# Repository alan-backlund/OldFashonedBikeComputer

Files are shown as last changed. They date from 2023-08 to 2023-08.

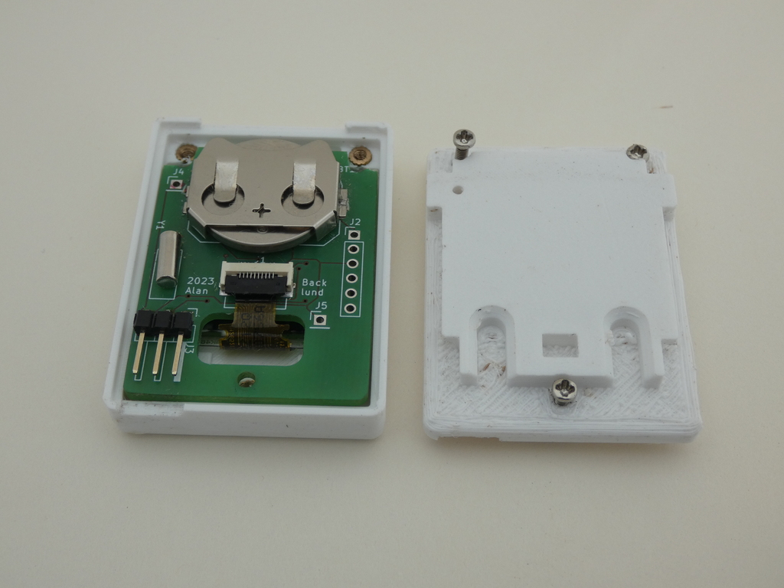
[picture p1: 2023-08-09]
Photos/P17.JPG

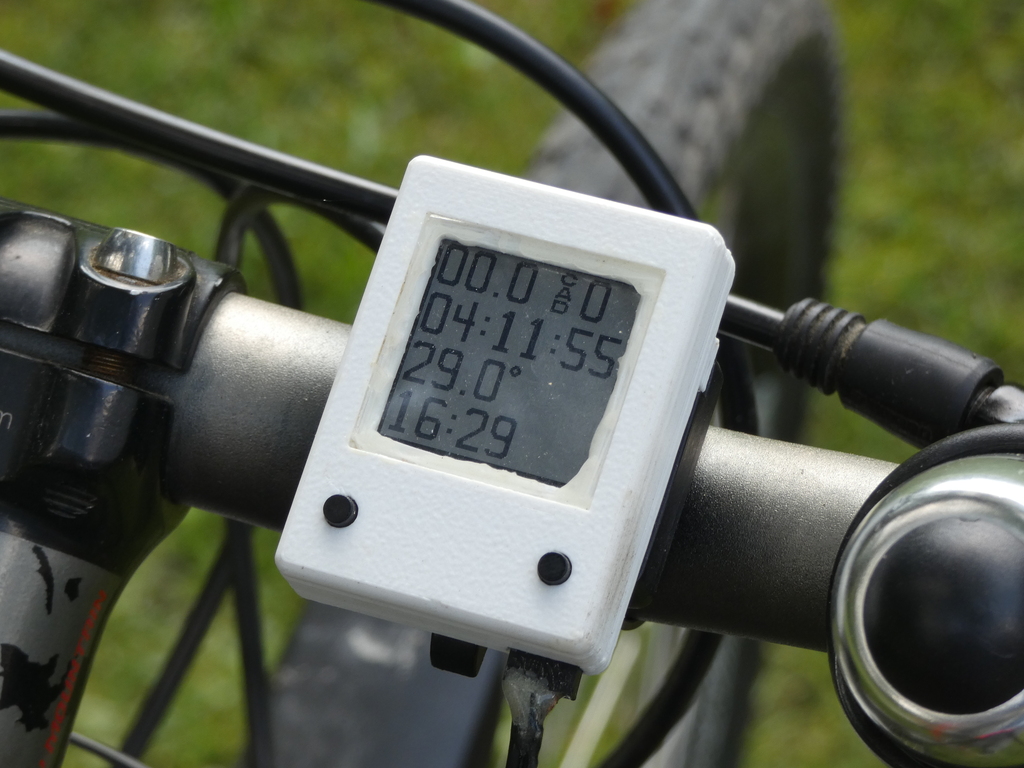
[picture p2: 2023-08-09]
Photos/P08.JPG

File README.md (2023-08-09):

# OldFashonedBikeComputer
Bicycle computer like they don't make anymore. Distance &amp; cadence and a battery that lasts years.

## Overview
OldFashonedBikeComputer (OFBC) is a bicycle computer based on the STM32L031 mpu and a Sharp LS013B7DH03 display. It monitors distance travelled, cadence and temperature. It fits in a small (35mm by 55mm) case and will hopefully run for two years on a CR2032 coin cell.

### The State of This Project
I have built a unit and am using it on my bike. IT works "Good enough" for my requirements so I am moving on to other projects for now. A number of options are set the way I like them and can only be changed by re-compiling the firmware.

### To Do
* Larger screen.
* Switch to a processor with more flash (32k is barely enough).
* More configuration items (kilometres/miles, Celsuis/Farenheit, 12hr/24hr).
* New PCB with the mounting holes in the right place. Original pcb has been literally hacked to fit.

## Contributing
If you have a suggestion for an improvement, please fork the repo and create a pull request. You can also simply open an issue or for more general feature requests, head over to the discussions.

## License
Distributed under the GPL v3 License.

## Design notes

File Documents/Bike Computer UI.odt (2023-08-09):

Bicycle Computer

User Interface

2023-08-09

# Initial Screen

Shows build Date

Exits when either key is pressed or either sensor is triggered.

# Prime screen

Shows items of interest while riding.

Currently Speed, cadence, ride duration, temperature and clock.

| Left Button | Right Button
Short Press | Switch to secondary screen | Not used
Long Press | Switch to setup selection screen | Reset Ride distance, time & max. speed

# Secondary Screen

Shows items of interest while stopped.

Currently ride distance, ride maximum speed, ride duration and odometer.

| Left Button | Right Button
Short Press | Switch to prime screen | Not used
Long Press | Switch to setup selection screen | Reset Ride distance, time & max. speed

# Setup Selection Screen

Used to select parameter to be set up.

| Left Button | Right Button
Short Press | Change selected item | Switch to selected item
Long Press | Not used | Return to primary or secondary screen

# Clock Setup Screen

Used to set clock.

| Left Button | Right Button
Short Press | Change selected item | Increment to selected item
Long Press | Not used | Return to primary or secondary screen

# Odometer Setup Screen

Used to set odometer.

| Left Button | Right Button
Short Press | Change selected item | Increment to selected item
Long Press | Not used | Return to primary or secondary screen

# Wheel Diameter Setup Screen

Used to set wheel diameter used to calculate distance.

| Left Button | Right Button
Short Press | Change selected item | Increment to selected item
Long Press | Not used | Return to primary or secondary screen

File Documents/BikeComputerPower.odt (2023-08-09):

Bike Computer Power

# 2032 Battery

3V lithium

210-230 mAh

# Power

July 25, 2023

| Mode | µAmps | Hours | Days
CPU | 2.097MHz | 500 | 440 | 18.33
| Sleep | 17 | 12941.18 | 539.22
Display | Run | 2
| Sleep | 0.02
Temperature | Run | 9
| Sleep | 0.1
Total | Run | 511 | 430.53 | 17.94
| Sleep | 17.12 | 12849.5 | 535.4

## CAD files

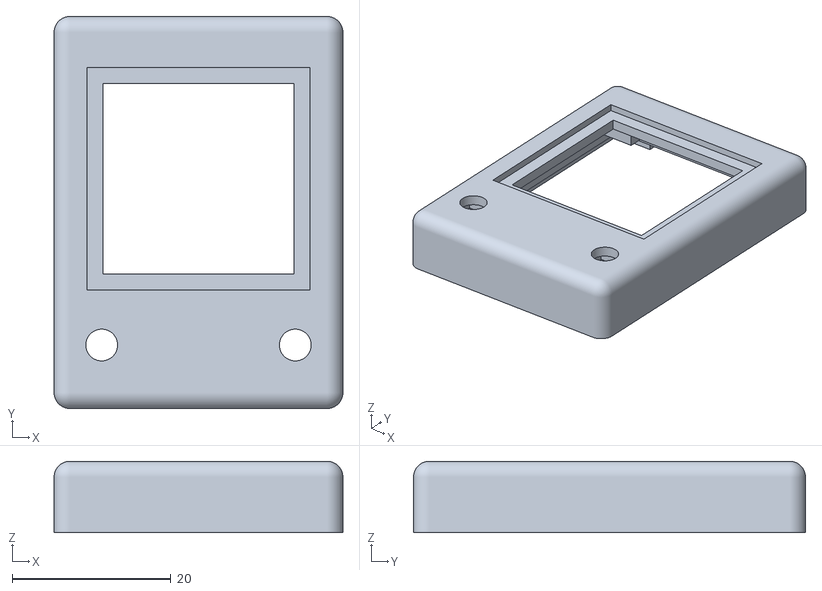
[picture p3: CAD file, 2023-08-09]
Case/caseTopV1.stl
36.4 x 49.4 x 9.00

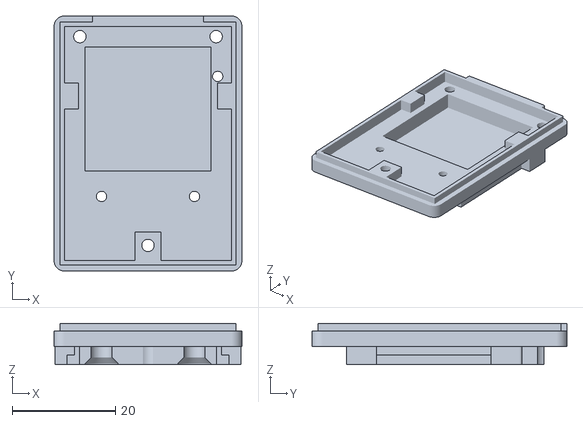
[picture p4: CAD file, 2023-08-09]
Case/caseBottomV1.stl
36.4 x 49.4 x 7.95

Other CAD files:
Case/caseTopV1.dxf

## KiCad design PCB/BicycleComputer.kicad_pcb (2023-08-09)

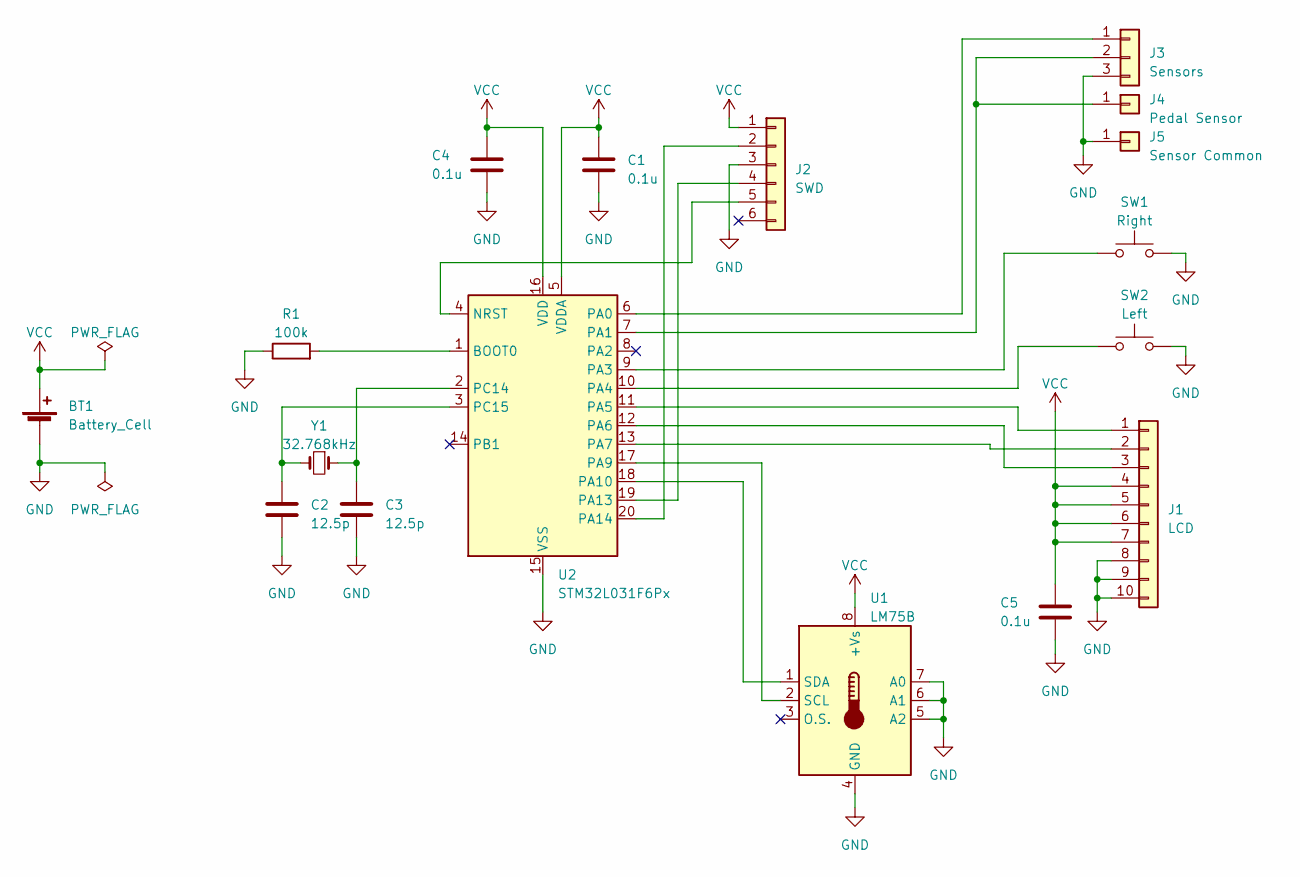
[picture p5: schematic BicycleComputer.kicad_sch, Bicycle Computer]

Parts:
BT1: Battery_Cell; BatteryHolder_Keystone_3034_1x20mm
C1, C4, C5: 0.1u; C_0805_2012Metric
C2, C3: 12.5p; C_0805_2012Metric
J1: LCD; Hirose_FH12-10S-0.5SH_1x10-1MP_P0.50mm_Horizontal
J2: SWD; PinHeader_1x06_P2.54mm_Vertical
J3: Sensors; PinHeader_1x03_P2.54mm_Horizontal
J4: Pedal Sensor; PinHeader_1x01_P2.54mm_Vertical
J5: Sensor Common; PinHeader_1x01_P2.54mm_Vertical
R1: 100k; R_0805_2012Metric
SW1: Right; SW_Push_1P1T_NO_6x6mm_H9.5mm
SW2: Left; SW_Push_1P1T_NO_6x6mm_H9.5mm
U1: LM75B; HVSSOP-8-1EP_3x3mm_P0.65mm_EP1.57x1.89mm
U2: STM32L031F6Px; TSSOP-20_4.4x6.5mm_P0.65mm
Y1: 32.768kHz; Crystal_C38-LF_D3.0mm_L8.0mm_Horizontal

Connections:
GND: BT1.2 (-), C1.2, C2.2, C3.2, C4.2, C5.2, J1.8, J1.9, J1.10, J2.3, J3.3, J5.1, R1.1, SW1.2, SW2.2, U1.4 (GND), U1.5 (A2), U1.6 (A1), U1.7 (A0), U2.15 (VSS)
unnamed: J1.1, U2.11 (PA5)
unnamed: J1.2, U2.13 (PA7)
unnamed: J1.3, U2.12 (PA6)
unnamed: J2.2, U2.20 (PA14)
unnamed: J2.4, U2.19 (PA13)
unnamed: J2.5, U2.4 (NRST)
unnamed: J3.1, U2.6 (PA0)
unnamed: J3.2, J4.1, U2.7 (PA1)
unnamed: U1.2 (SCL), U2.17 (PA9)
unnamed: U1.1 (SDA), U2.18 (PA10)
unnamed: R1.2, U2.1 (BOOT0)
unnamed: SW1.1, U2.9 (PA3)
unnamed: SW2.1, U2.10 (PA4)
unnamed: C3.1, U2.2 (PC14), Y1.1
unnamed: C2.1, U2.3 (PC15), Y1.2
VCC: BT1.1 (+), C1.1, C4.1, C5.1, J1.4, J1.5, J1.6, J1.7, J2.1, U1.8 (+Vs), U2.5 (VDDA), U2.16 (VDD)

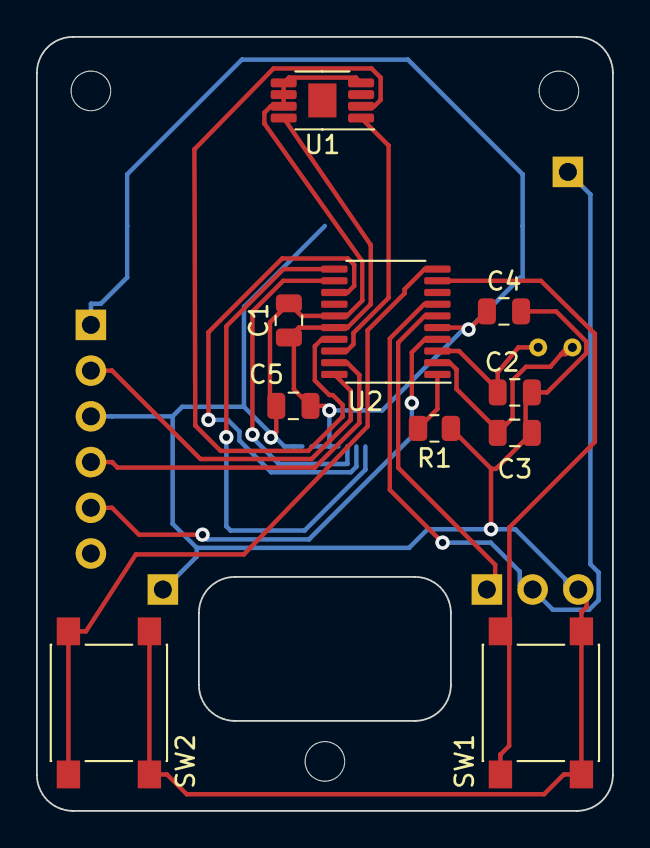
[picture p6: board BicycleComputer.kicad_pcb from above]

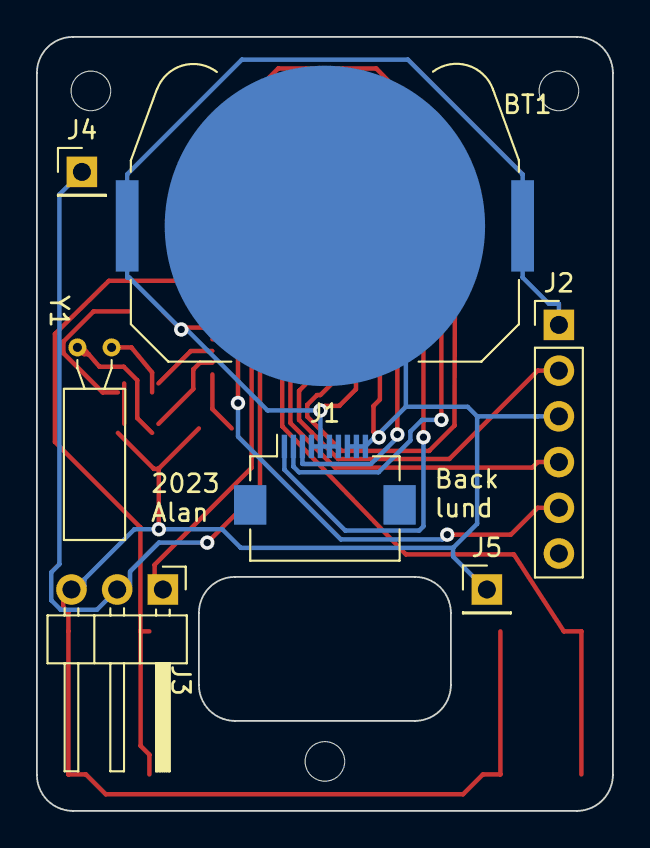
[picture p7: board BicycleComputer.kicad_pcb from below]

Board: 2 copper layers, 32.0 x 43.0 mm, 20 parts (7 on the bottom side), 17 nets.

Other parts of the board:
REF00, REF01, REF02: MountingHole_2.2mm_M2

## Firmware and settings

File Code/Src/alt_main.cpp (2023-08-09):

/* Includes ------------------------------------------------------------------*/
#include "alt_main.h"

/* Private includes ----------------------------------------------------------*/
#include "monitor.hpp"
#include "sharp_display.h"
#include <Temperature_LM75_Derived.h>
#include "bitmaps.h"
#include "gpio.h"
#include "spi.h"
#include "rtc.h"
#include "main.h"


/* Private typedef -----------------------------------------------------------*/

typedef struct
{
	uint16_t Pin;
	GPIO_PinState Value;
	uint32_t Time;
} SwitchTime_t;

typedef struct {
	uint8_t hours;
	uint8_t minutes;
	uint8_t seconds;
} TOD_t;

enum class State_t { STOPPED, RUNNING, SETUP };

enum class Command_t { LEFT_SHORT, LEFT_LONG, RIGHT_SHORT, RIGHT_LONG };

enum class Display_t { RIDE, INFO };

enum class SetUpScreen_t { MAIN, CLOCK, ODO, WHEEL };

/* Private define ------------------------------------------------------------*/

#define USE_SLEEP	1

#define SHORT_MIN	100	// mS
#define SHORT_MAX	800
#define LONG_MIN	1000
#define LONG_MAX	3500

#define CHECK			0xAB200723
#define CHECK_ADR		0x08080000
#define WHEEL_ADR		(CHECK_ADR + 4)
#define ODOMETER_ADR	(CHECK_ADR + 8)

#define readFromEEPROMi16(address)		(*(__IO int16_t *)(address))
#define readFromEEPROMu32(address)		(*(__IO uint32_t *)(address))

/* Private macro -------------------------------------------------------------*/

/* Private variables ---------------------------------------------------------*/
cMonitor monitor;
sharp_display display(SPI1_CS_GPIO_Port, SPI1_CS_Pin, &hspi1);
Generic_LM75_11Bit temperature(&hi2c1);

volatile State_t systemState = State_t::STOPPED;

#if 0
volatile SwitchTime_t controlQ[16];
volatile uint8_t controlH = 0, controlT = 0;
#else
GPIO_PinState leftLastState = GPIO_PIN_SET;
GPIO_PinState rightLastState = GPIO_PIN_SET;
#endif
volatile SwitchTime_t sensorQ[16];
volatile uint8_t sensorH = 0, sensorT = 0;
volatile uint32_t lastCqTime = 0;

volatile uint32_t Distance = 0;
volatile uint32_t SpdLastTime = 0;
volatile uint32_t Speed = 0;
volatile uint32_t MaximumSpeed = 0;
volatile uint32_t CadLastTime = 0;
volatile uint32_t Cadence = 0;
volatile uint32_t Duration = 0;
volatile uint32_t Odometer = 0;

volatile uint32_t leftStartTime = 0;
volatile uint32_t rightStartTime = 0;

volatile Display_t currentDisplay = Display_t::RIDE;

volatile SetUpScreen_t setupScreen = SetUpScreen_t::MAIN;
volatile uint8_t setupSelection = 0;

volatile int16_t wheelDiameter = 2125;

char clockText[] = "24:00";
char OdometerText[] = "0000.0";
char wheelDiameterText[] = "2125";

/* Private function prototypes -----------------------------------------------*/

/* Private user code ---------------------------------------------------------*/

void drawSpeed(int16_t x, int16_t y)
{
	display.drawBitmap(&x, y, &bitmaps32[(Speed/100)%10]);
	display.drawBitmap(&x, y, &bitmaps32[(Speed/10)%10]);
	display.drawBitmap(&x, y, &bitmaps32[period_idx]);
	display.drawBitmap(&x, y, &bitmaps32[(Speed/1)%10]);
}

void drawMaximumSpeed(int16_t x, int16_t y)
{
	display.drawBitmap(&x, y, &bitmaps32[max_idx]);
	display.drawBitmap(&x, y, &bitmaps32[(MaximumSpeed/100)%10]);
	display.drawBitmap(&x, y, &bitmaps32[(MaximumSpeed/10)%10]);
	display.drawBitmap(&x, y, &bitmaps32[period_idx]);
	display.drawBitmap(&x, y, &bitmaps32[(MaximumSpeed/1)%10]);
}

void drawCadence(int16_t x, int16_t y)
{
	display.drawBitmap(&x, y, &bitmaps32[cad_idx]);
	uint32_t d = (Cadence/100)%10;
	if (d != 0)
		display.drawBitmap(&x, y, &bitmaps32[d]);
	d = (Cadence/10)%10;
	if (d != 0)
		display.drawBitmap(&x, y, &bitmaps32[d]);
	display.drawBitmap(&x, y, &bitmaps32[(Cadence/1)%10]);
}

void drawDistance(int16_t x, int16_t y)
{
	display.drawBitmap(&x, y, &bitmaps32[dst_idx]);
	uint32_t dist = Distance*wheelDiameter/10000;
	uint32_t d = (dist/10000)%10;
	if (d != 0)
		display.drawBitmap(&x, y, &bitmaps32[d]);
	d = (dist/1000)%10;
	if (d != 0)
		display.drawBitmap(&x, y, &bitmaps32[d]);
	display.drawBitmap(&x, y, &bitmaps32[(dist/100)%10]);
	display.drawBitmap(&x, y, &bitmaps32[period_idx]);
	display.drawBitmap(&x, y, &bitmaps32[(dist/10)%10]);
	display.drawBitmap(&x, y, &bitmaps32[(dist/1)%10]);
}

void drawDuration(int16_t x, int16_t y)
{
	int t = Duration / 1000;
	int s = t % 60;
	t = t / 60;
	int m = t % 60;
	int h = t / 60;

	display.drawBitmap(&x, y, &bitmaps32[(h/10)%10]);
	display.drawBitmap(&x, y, &bitmaps32[h%10]);
	display.drawBitmap(&x, y, &bitmaps32[colon_idx]);
	display.drawBitmap(&x, y, &bitmaps32[(m/10)%10]);
	display.drawBitmap(&x, y, &bitmaps32[m%10]);
	display.drawBitmap(&x, y, &bitmaps32[colon_idx]);
	display.drawBitmap(&x, y, &bitmaps32[(s/10)%10]);
	display.drawBitmap(&x, y, &bitmaps32[s%10]);
}

void drawTime(int16_t x, int16_t y)
{
	RTC_DateTypeDef sdatestructureget;
	RTC_TimeTypeDef stimestructureget;
	HAL_RTC_GetTime(&hrtc, &stimestructureget, RTC_FORMAT_BIN);
	HAL_RTC_GetDate(&hrtc, &sdatestructureget, RTC_FORMAT_BIN);
	display.drawBitmap(&x, y, &bitmaps32[(stimestructureget.Hours/10)%10]);
	display.drawBitmap(&x, y, &bitmaps32[stimestructureget.Hours%10]);
	display.drawBitmap(&x, y, &bitmaps32[colon_idx]);
	display.drawBitmap(&x, y, &bitmaps32[(stimestructureget.Minutes/10)%10]);
	display.drawBitmap(&x, y, &bitmaps32[stimestructureget.Minutes%10]);
}

void drawTemperature(int16_t x, int16_t y)
{
	temperature.disableShutdownMode();
	HAL_Delay(10);
	float t = temperature.readTemperatureC();
	temperature.enableShutdownMode();

	if (t < 0)
		t = -t;
	display.drawBitmap(&x, y, &bitmaps32[((int)t/10)%10]);
	display.drawBitmap(&x, y, &bitmaps32[(int)t%10]);
	display.drawBitmap(&x, y, &bitmaps32[period_idx]);
	display.drawBitmap(&x, y, &bitmaps32[(int)(t*10)%10]);
	display.drawBitmap(&x, y, &bitmaps32[degree_idx]);
}

void drawOdometer(int16_t x, int16_t y)
{
	display.drawBitmap(&x, y, &bitmaps32[odo_idx]);
	uint32_t dist = Odometer*wheelDiameter/100000;
	uint32_t d = (dist/10000)%10;
	if (d != 0)
		display.drawBitmap(&x, y, &bitmaps32[d]);
	d = (dist/1000)%10;
	if (d != 0)
		display.drawBitmap(&x, y, &bitmaps32[d]);
	d = (dist/100)%10;
	if (d != 0)
		display.drawBitmap(&x, y, &bitmaps32[d]);
	display.drawBitmap(&x, y, &bitmaps32[(dist/10)%10]);
	display.drawBitmap(&x, y, &bitmaps32[period_idx]);
	display.drawBitmap(&x, y, &bitmaps32[(dist/1)%10]);
}

void DisplaySetup()
{
	switch (setupScreen) {
	case SetUpScreen_t::MAIN:
		display.clearDisplay();
		display.drawBitmap(0, setupSelection*32, bitmaps32[rarrow_idx].bitmap, 18, 32, 0);
		display.drawString(18, 0, bitmaps32, (char *)"CLOCK");
		display.drawString(18, 32, bitmaps32, (char *)"ODO");
		display.drawString(18, 64, bitmaps32, (char *)"WHEEL");
		display.refresh();
		break;
	case SetUpScreen_t::CLOCK: {
		RTC_DateTypeDef sdatestructureget;
		RTC_TimeTypeDef stimestructureget;
		HAL_RTC_GetTime(&hrtc, &stimestructureget, RTC_FORMAT_BIN);
		HAL_RTC_GetDate(&hrtc, &sdatestructureget, RTC_FORMAT_BIN);
		clockText[0] = '0' + stimestructureget.Hours / 10;
		clockText[1] = '0' + stimestructureget.Hours % 10;
		clockText[2] = ':';
		clockText[3] = '0' + stimestructureget.Minutes / 10;
		clockText[4] = '0' + stimestructureget.Minutes % 10;
		display.clearDisplay();
		display.drawString(0, 0, bitmaps32, (char *)"CLOCK");
		display.drawString(0, 32, bitmaps32, clockText);
		display.drawBitmap(setupSelection*18, 64, bitmaps32[uarrow_idx].bitmap, 18, 32, 0);
		display.refresh();
	} break;
	case SetUpScreen_t::ODO: {
		uint32_t odo = Odometer*wheelDiameter/100000;
		OdometerText[0] = '0' + odo/10000;
		OdometerText[1] = '0' + (odo/1000) % 10;
		OdometerText[2] = '0' + (odo/100) % 10;
		OdometerText[3] = '0' + (odo/10) % 10;
		OdometerText[4] = '.';
		OdometerText[5] = '0' + odo % 10;
		display.clearDisplay();
		display.drawString(0, 0, bitmaps32, (char *)"ODO");
		display.drawString(0, 32, bitmaps32, OdometerText);
		display.drawBitmap(setupSelection*18, 64, bitmaps32[uarrow_idx].bitmap, 18, 32, 0);
		display.refresh();
	} break;
	case SetUpScreen_t::WHEEL:
		wheelDiameterText[0] = '0' + wheelDiameter/1000;
		wheelDiameterText[1] = '0' + (wheelDiameter/100) % 10;
		wheelDiameterText[2] = '0' + (wheelDiameter/10) % 10;
		wheelDiameterText[3] = '0' + wheelDiameter % 10;
		display.clearDisplay();
		display.drawString(0, 0, bitmaps32, (char *)"WHEEL");
		display.drawString(0, 32, bitmaps32, wheelDiameterText);
		display.drawBitmap(setupSelection*18, 64, bitmaps32[uarrow_idx].bitmap, 18, 32, 0);
		display.refresh();
		break;
	}
}

void CommandProcess(Command_t cmd)
{
	if (systemState != State_t::SETUP) {
		if (cmd == Command_t::RIGHT_LONG) {
			// reset time and CadCount
			Distance = 0;
			MaximumSpeed = 0;
			Duration = 0;
			monitor.schedule((char*)"DisplayUpdate", 0);
		} else if (cmd == Command_t::LEFT_SHORT) {
			if (currentDisplay == Display_t::RIDE)
				currentDisplay = Display_t::INFO;
			else
				currentDisplay = Display_t::RIDE;
			monitor.schedule((char*)"DisplayUpdate", 0);
		} else if (cmd == Command_t::LEFT_LONG) {
			systemState = State_t::SETUP;
			monitor.schedule((char*)"DisplayUpdate", NEVER);
			setupScreen = SetUpScreen_t::MAIN;
			setupSelection = 0;
			DisplaySetup();
		} else if (cmd == Command_t::RIGHT_SHORT) {
		}
	} else {
		if (cmd == Command_t::RIGHT_SHORT) {
			if (setupScreen == SetUpScreen_t::MAIN) {
				if (setupSelection == 0)
					setupScreen = SetUpScreen_t::CLOCK;
				else if (setupSelection == 1)
					setupScreen = SetUpScreen_t::ODO;
				else if (setupSelection == 2)
					setupScreen = SetUpScreen_t::WHEEL;
				setupSelection = 0;
				DisplaySetup();
			} else if (setupScreen == SetUpScreen_t::CLOCK) {
				// Change clock displayed value
				if (setupSelection == 0) {
					clockText[0]++;
					if (clockText[0] == '2' + 1)
						clockText[0] = '0';
				} else if (setupSelection == 1) {
					clockText[1]++;
					if (clockText[0] != '2') {
						if (clockText[1] == '9' + 1)
							clockText[1] = '0';
					} else {
						if (clockText[1] == '3' + 1)
							clockText[1] = '0';
					}
				} else if (setupSelection == 2) {
					clockText[3]++;
					if (clockText[3] == '5' + 1)
						clockText[3] = '0';
				} else if (setupSelection == 3) {
					clockText[4]++;
					if (clockText[4] == '9' + 1)
						clockText[4] = '0';
				}
				display.clearBlock(setupSelection*18 + ((setupSelection>1)?9:0), 32, 18, 32);
				display.drawString(0, 32, bitmaps32, clockText);
				display.refresh();
			} else if (setupScreen == SetUpScreen_t::ODO) {
				// Change odometer displayed value
				int ts = setupSelection + (setupSelection==4 ? 1:0);
				OdometerText[ts]++;
				if (OdometerText[ts] == '9' + 1)
					OdometerText[ts] = '0';
				display.clearBlock(ts*18, 32, 18, 32);
				display.drawString(0, 32, bitmaps32, OdometerText);
				display.refresh();
			} else if (setupScreen == SetUpScreen_t::WHEEL) {
				// Change wheel diameter displayed value
				wheelDiameterText[setupSelection]++;
				if (wheelDiameterText[setupSelection] == '9' + 1)
					wheelDiameterText[setupSelection] = '0';
				display.clearBlock(setupSelection*18, 32, 18, 32);
				display.drawString(0, 32, bitmaps32, wheelDiameterText);
				display.refresh();
			}
		} else if (cmd == Command_t::RIGHT_LONG) {
			if (setupScreen == SetUpScreen_t::CLOCK) {
				// Update clock value from display
				RTC_DateTypeDef sdatestructureget;
				RTC_TimeTypeDef stimestructureget;
				HAL_RTC_GetTime(&hrtc, &stimestructureget, RTC_FORMAT_BIN);
				HAL_RTC_GetDate(&hrtc, &sdatestructureget, RTC_FORMAT_BIN);
				stimestructureget.Hours = (clockText[0] - '0') * 10 + (clockText[1] - '0');
				stimestructureget.Minutes = (clockText[3] - '0') * 10 + (clockText[4] - '0');
				HAL_RTC_SetTime(&hrtc, &stimestructureget, RTC_FORMAT_BIN);
			} else if (setupScreen == SetUpScreen_t::ODO) {
				// Update odometer value from display
				uint32_t odo = (OdometerText[0] - '0') * 10000
						+ (OdometerText[1] - '0') * 1000
						+ (OdometerText[2] - '0') * 100
						+ (OdometerText[3] - '0') * 10
						+ (OdometerText[5] - '0');
				Odometer = odo*100000/wheelDiameter;
			} else if (setupScreen == SetUpScreen_t::WHEEL) {
				// Update wheel diameter value from display
				wheelDiameter = (wheelDiameterText[0] - '0') * 1000
						+ (wheelDiameterText[1] - '0') * 100
						+ (wheelDiameterText[2] - '0') * 10
						+ (wheelDiameterText[3] - '0');
				if (HAL_FLASHEx_DATAEEPROM_Unlock() == HAL_OK) {
					HAL_FLASHEx_DATAEEPROM_Program(FLASH_TYPEPROGRAMDATA_HALFWORD, WHEEL_ADR, wheelDiameter);
					HAL_FLASHEx_DATAEEPROM_Lock();
				}
			}

			systemState = State_t::RUNNING;
			monitor.schedule((char*)"DisplayUpdate", 0);
		} else if (cmd == Command_t::LEFT_SHORT) {
			if (setupScreen == SetUpScreen_t::MAIN) {
				display.drawBitmap(0, setupSelection*32, bitmaps32[rarrow_idx].bitmap, 18, 32, 1);
				setupSelection = (setupSelection + 1) % 3;
				display.drawBitmap(0, setupSelection*32, bitmaps32[rarrow_idx].bitmap, 18, 32, 0);
				display.refresh();
			} else if (setupScreen == SetUpScreen_t::CLOCK) {
				int16_t p = setupSelection * 18 + (setupSelection>1 ? 9 : 0);
				display.drawBitmap(p, 64, bitmaps32[uarrow_idx].bitmap, 18, 32, 1);
				setupSelection = (setupSelection + 1) % 4;
				p = setupSelection * 18 + ((setupSelection > 1) ? 9 : 0);
				display.drawBitmap(p, 64, bitmaps32[uarrow_idx].bitmap, 18, 32, 0);
				display.refresh();
			} else if (setupScreen == SetUpScreen_t::ODO) {
				int16_t p = setupSelection * 18 + (setupSelection>3 ? 9 : 0);
				display.drawBitmap(p, 64, bitmaps32[uarrow_idx].bitmap, 18, 32, 1);
				setupSelection = (setupSelection + 1) % 5;
				p = setupSelection * 18 + (setupSelection>3 ? 9 : 0);
				display.drawBitmap(p, 64, bitmaps32[uarrow_idx].bitmap, 18, 32, 0);
				display.refresh();
			} else if (setupScreen == SetUpScreen_t::WHEEL) {
				display.drawBitmap(setupSelection*18, 64, bitmaps32[uarrow_idx].bitmap, 18, 32, 1);
				setupSelection = (setupSelection + 1) % 4;
				display.drawBitmap(setupSelection*18, 64, bitmaps32[uarrow_idx].bitmap, 18, 32, 0);
				display.refresh();
			}
		} else if (cmd == Command_t::LEFT_LONG) {
		}
	}
}

timeInterval_t DisplayUpdate()
{
	uint32_t start = HAL_GetTick();

	if (Speed < 20) {
		Speed = 0;
		Cadence = 0;
	}
	if (Cadence < 20)
		Cadence = 0;
	if (systemState != State_t::STOPPED)
		Duration += 1000;

	display.clearDisplayBuffer();
	if (currentDisplay == Display_t::RIDE) {
		drawSpeed(0, 0);
		drawCadence(128-54, 0);
		drawTime(0, 128-1*32);
		drawTemperature(0, 128-2*32);
		drawDuration(0, 32);
	} else {
		drawDistance(0, 0);
		drawMaximumSpeed(0, 32);
		drawDuration(0, 32*2);
		drawOdometer(0, 32*3);
	}
	display.refresh();

	if (Speed > 0) {
		// calculate speed for next update, if no sensor update occurs
		RTC_TimeTypeDef stime;
		RTC_DateTypeDef sdate;
		HAL_RTC_GetTime(&hrtc, &stime, RTC_FORMAT_BIN);
		HAL_RTC_GetDate(&hrtc, &sdate, RTC_FORMAT_BIN);
		uint32_t now = stime.Hours * 1000 * 60 * 60;
		now += stime.Minutes * 1000 * 60;
		now += stime.Seconds * 1000;
		now += 1000 * (stime.SecondFraction - stime.SubSeconds) / (stime.SecondFraction + 1);
		Speed = ((uint32_t)(wheelDiameter*3.6*10))/(now - SpdLastTime);
	} else {
		systemState = State_t::STOPPED;
		if (HAL_FLASHEx_DATAEEPROM_Unlock() == HAL_OK) {
			HAL_FLASHEx_DATAEEPROM_Program(FLASH_TYPEPROGRAMDATA_WORD, ODOMETER_ADR, Odometer);
			HAL_FLASHEx_DATAEEPROM_Lock();
		}

		return NEVER;
	}

	if (Cadence > 0) {
		// calculate cadence for next update, if no sensor update occurs
		RTC_TimeTypeDef stime;
		RTC_DateTypeDef sdate;
		HAL_RTC_GetTime(&hrtc, &stime, RTC_FORMAT_BIN);
		HAL_RTC_GetDate(&hrtc, &sdate, RTC_FORMAT_BIN);
		uint32_t now = stime.Hours * 1000 * 60 * 60;
		now += stime.Minutes * 1000 * 60;
		now += stime.Seconds * 1000;
		now += 1000 * (stime.SecondFraction - stime.SubSeconds) / (stime.SecondFraction + 1);
		Cadence = 60000 / (sensorQ[sensorH].Time - CadLastTime);
	}

	return 1000 - (HAL_GetTick() - start);
}

timeInterval_t ControlUpdateLeft()
{
	timeInterval_t result = NEVER;
	if ((leftLastState == GPIO_PIN_SET) && (HAL_GPIO_ReadPin(GPIOA, LEFT_Pin) == GPIO_PIN_RESET)) {
		// left button has closed
		leftStartTime = HAL_GetTick();
		leftLastState = GPIO_PIN_RESET;
		result = 20;
	} else if ((leftLastState == GPIO_PIN_RESET) && (HAL_GPIO_ReadPin(GPIOA, LEFT_Pin) == GPIO_PIN_RESET)) {
		// left button still closed
		result = 20;
	} else if ((leftLastState == GPIO_PIN_RESET) && (HAL_GPIO_ReadPin(GPIOA, LEFT_Pin) == GPIO_PIN_SET)) {
		// left button has opened
		uint32_t dur = HAL_GetTick() - leftStartTime;
		leftStartTime = HAL_GetTick();
		if ((dur >= SHORT_MIN) && (dur <= SHORT_MAX))
			CommandProcess(Command_t::LEFT_SHORT);
		if ((dur >= LONG_MIN) && (dur <= LONG_MAX))
			CommandProcess(Command_t::LEFT_LONG);
		leftLastState = GPIO_PIN_SET;
		result = 20;
	} // else left button still opened => done (return NEVER)
	return result;
}

timeInterval_t ControlUpdateRight()
{
	timeInterval_t result = NEVER;
	if ((rightLastState == GPIO_PIN_SET) && (HAL_GPIO_ReadPin(GPIOA, RIGHT_Pin) == GPIO_PIN_RESET)) {
		// right button has closed
		rightStartTime = HAL_GetTick();
		rightLastState = GPIO_PIN_RESET;
		result = 20;
	} else if ((rightLastState == GPIO_PIN_RESET) && (HAL_GPIO_ReadPin(GPIOA, RIGHT_Pin) == GPIO_PIN_RESET)) {
		// right button still closed
		result = 20;
	} else if ((rightLastState == GPIO_PIN_RESET) && (HAL_GPIO_ReadPin(GPIOA, RIGHT_Pin) == GPIO_PIN_SET)) {
		// right button has opened
		uint32_t dur = HAL_GetTick() - rightStartTime;
		rightStartTime = HAL_GetTick();
		if ((dur >= SHORT_MIN) && (dur <= SHORT_MAX))
			CommandProcess(Command_t::RIGHT_SHORT);
		if ((dur >= LONG_MIN) && (dur <= LONG_MAX))
			CommandProcess(Command_t::RIGHT_LONG);
		rightLastState = GPIO_PIN_SET;
		result = 20;
	} // else right button still opened => done (return NEVER)
	return result;
}

timeInterval_t SensorUpdate()
{
	while (sensorH != sensorT) {
		if (sensorQ[sensorH].Pin == WHEEL_Pin) {
			if (systemState == State_t::RUNNING) {
				// max speed: 7.65/60kph => 0.1275s
				if ((sensorQ[sensorH].Time - SpdLastTime) > 127) {
					Speed = ((uint32_t)(wheelDiameter*3.6*10))/(sensorQ[sensorH].Time - SpdLastTime);
					if (Speed > MaximumSpeed)
						MaximumSpeed = Speed;
					Distance++;
					Odometer++;
					SpdLastTime = sensorQ[sensorH].Time;
				}
			} else if (systemState == State_t::STOPPED) {
				Speed = 1;
				SpdLastTime = sensorQ[sensorH].Time;
				systemState = State_t::RUNNING;
				monitor.schedule((char*)"DisplayUpdate", 500);
			}
			// else if CONTROL then do nothing
		}
		// max rpm: 60/300rpm => 0.2s
		if ((sensorQ[sensorH].Pin == PEDAL_Pin) && ((sensorQ[sensorH].Time - CadLastTime) > 200)) {
			Cadence = 60000 / (sensorQ[sensorH].Time - CadLastTime);
			CadLastTime = sensorQ[sensorH].Time;
		}
		sensorH = (sensorH + 1) & 0xF;
	}
	return NEVER;
}


task_t TasksTable[] = {
	{ (char *)"DisplayUpdate", DisplayUpdate, NEVER, false },
	{ (char *)"ControlUpdateLeft", ControlUpdateLeft, NEVER, false },
	{ (char *)"ControlUpdateRight", ControlUpdateRight, NEVER, false },
	{ (char *)"SensorUpdate", SensorUpdate, NEVER, false },
};

/**
  * @brief  System Clock Configuration
  *         The system Clock is configured as follow :
  *            System Clock source            = MSI
  *            MSI Range                      = 0
  *            SYSCLK(Hz)                     = 64000
  *            HCLK(Hz)                       = 32000
  *            AHB Prescaler                  = 2
  *            APB1 Prescaler                 = 1
  *            APB2 Prescaler                 = 1
  *            Main regulator output voltage  = Scale2 mode
  * @param  None
  * @retval None
  */
void SystemClock_Decrease(void)
{
	RCC_ClkInitTypeDef RCC_ClkInitStruct = {0};
	RCC_OscInitTypeDef RCC_OscInitStruct = {0};
	/* Enable Power Control clock */
	__HAL_RCC_PWR_CLK_ENABLE();

	/* The voltage scaling allows optimizing the power consumption when the device is
	 clocked below the maximum system frequency, to update the voltage scaling value
	 regarding system frequency refer to product datasheet.  */
	__HAL_PWR_VOLTAGESCALING_CONFIG(PWR_REGULATOR_VOLTAGE_SCALE2);

	/* Enable MSI Oscillator */
	RCC_OscInitStruct.OscillatorType = RCC_OSCILLATORTYPE_MSI;
	RCC_OscInitStruct.MSIState = RCC_MSI_ON;
	RCC_OscInitStruct.MSIClockRange       = RCC_MSIRANGE_5; /* Set temporary MSI range */
	RCC_OscInitStruct.MSICalibrationValue = RCC_MSICALIBRATION_DEFAULT;
	RCC_OscInitStruct.PLL.PLLState = RCC_PLL_NONE;
	if (HAL_RCC_OscConfig(&RCC_OscInitStruct)!= HAL_OK)
		Error_Handler();

	/* Select MSI as system clock source and configure the HCLK, PCLK1 and PCLK2
	 clocks dividers */
	RCC_ClkInitStruct.ClockType = (RCC_CLOCKTYPE_SYSCLK | RCC_CLOCKTYPE_HCLK | RCC_CLOCKTYPE_PCLK1 | RCC_CLOCKTYPE_PCLK2);
	RCC_ClkInitStruct.SYSCLKSource = RCC_SYSCLKSOURCE_MSI;
	RCC_ClkInitStruct.AHBCLKDivider = RCC_SYSCLK_DIV2;
	RCC_ClkInitStruct.APB1CLKDivider = RCC_HCLK_DIV1;
	RCC_ClkInitStruct.APB2CLKDivider = RCC_HCLK_DIV1;
	if (HAL_RCC_ClockConfig(&RCC_ClkInitStruct, FLASH_LATENCY_0)!= HAL_OK)
		Error_Handler();

	/* Set Final MSI range */
	/* Set MSI range to 0 */
	__HAL_RCC_MSI_RANGE_CONFIG(RCC_MSIRANGE_0);

	/* Configure the SysTick to have interrupt in 10 ms time basis*/
	HAL_SYSTICK_Config(HAL_RCC_GetHCLKFreq()/100);
}
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

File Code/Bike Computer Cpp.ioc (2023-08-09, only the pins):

Mcu.UserName=STM32L031F6Px
PA0-CK_IN.GPIO_Label=WHEEL
PA0-CK_IN.Signal=GPXTI0
PA1.GPIO_Label=PEDAL
PA1.Signal=GPXTI1
PA10.Signal=I2C1_SDA
PA13.Signal=SYS_SWDIO
PA14.Signal=SYS_SWCLK
PA2.Signal=GPIO_Analog
PA3.GPIO_Label=RIGHT
PA3.Signal=GPXTI3
PA4.GPIO_Label=LEFT
PA4.Signal=GPXTI4
PA5.Signal=SPI1_SCK
PA6.GPIO_Label=SPI1_CS
PA6.Signal=GPIO_Output
PA7.Signal=SPI1_MOSI
PA9.Signal=I2C1_SCL
PB1.Signal=GPIO_Analog
PC14-OSC32_IN.Signal=RCC_OSC32_IN
PC15-OSC32_OUT.Signal=RCC_OSC32_OUT

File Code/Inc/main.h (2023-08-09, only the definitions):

#define WHEEL_Pin GPIO_PIN_0
#define WHEEL_GPIO_Port GPIOA
#define WHEEL_EXTI_IRQn EXTI0_1_IRQn
#define PEDAL_Pin GPIO_PIN_1
#define PEDAL_GPIO_Port GPIOA
#define PEDAL_EXTI_IRQn EXTI0_1_IRQn
#define RIGHT_Pin GPIO_PIN_3
#define RIGHT_GPIO_Port GPIOA
#define RIGHT_EXTI_IRQn EXTI2_3_IRQn
#define LEFT_Pin GPIO_PIN_4
#define LEFT_GPIO_Port GPIOA
#define LEFT_EXTI_IRQn EXTI4_15_IRQn
#define SPI1_CS_Pin GPIO_PIN_6
#define SPI1_CS_GPIO_Port GPIOA

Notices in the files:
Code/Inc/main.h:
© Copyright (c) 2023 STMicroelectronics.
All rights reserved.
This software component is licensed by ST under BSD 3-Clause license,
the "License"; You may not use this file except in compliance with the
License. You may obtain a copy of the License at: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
